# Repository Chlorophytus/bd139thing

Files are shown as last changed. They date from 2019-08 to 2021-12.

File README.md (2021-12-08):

# bd139thing

The BD139 Thing is a 300mW RMS stereo Hi-Fi Class-A amplifier.

It is pairable with a set of very high sensitivity (>90dB) speakers for audio playback.

Distortion analysis has not been done yet, but [THD][total-harmonic-distortion]/[IMD][intermodulation-distortion] is probably 5-10%; most of it is pleasing "tube sound like" distortion, transistorized.

## Current state

I am working on another revision of the design.
The BD139 cascode is modular, meaning it can have many in parallel when paired with a suitable power supply and power filtering capacitors.
Heat dissipation on the negative feedback shunts and power delivery are primary concerns.

[total-harmonic-distortion]: https://en.wikipedia.org/wiki/Total_harmonic_distortion
[intermodulation-distortion]: https://en.wikipedia.org/wiki/Intermodulation

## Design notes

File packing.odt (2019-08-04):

Hey, so you ordered a BD139 Thing. Here’s a Bill of Materials for your convenience, containing part numbers and stuff. A packing list is supplied with this.

If you want to mess around with the design, feel free to contact me.

You can also get the Gerber/KiCad files from the Chlorophytus git repos:

git://git.chlorophyt.us/bd139thing.git

– Roland M.

INSTRUCTIONS ON MAKING:

1. Solder non-power resistors: R1/R2/R3/R4/R6/R7/R8/R9/R11
2. Solder LED: D1
3. Solder headphone jack: J1
4. Solder power jack: J2
5. Solder power resistors: R5/R10
6. Solder speaker terminal blocks: LS1/LS2
7. Solder SMALL capacitors, 47uF: C1/C3
8. Solder BIG capacitors, 2200uF: C2/C4
9. Solder the PN2222s (Q1/Q4) first then the BD139s (Q2/Q3/Q5/Q6)
10. Apply the heatsink on the exposed square.

NOTES:

Use bookshelf speakers that are 4-8 ohms. I don’t have any recommendations.

Use a 9V >3A power supply, center positive.

https://www.digikey.com/product-detail/en/cui-inc/SMI36-9-V-P5/102-3835-ND/5417696

BD139 Thing version v6.0 – packing list

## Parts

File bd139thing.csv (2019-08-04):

Manufacturer Part Number | Digi-Key Part Number | Customer Reference | Quantity
ECA-1HHG222 | P5576-ND | C2/C4 | 2
ECA-1HHG470 | P5570-ND | C1/C3 | 2
1984617 | 277-1721-ND | LS1/LS2 | 2
SJ1-3523NG | CP1-3523NG-ND | J1 | 1
PJ-037A | CP-037A-ND | J2 | 1
BD13916S | BD13916S-ND | Q2/Q3/Q5/Q6 | 4
PN2222ABU | PN2222AFS-ND | Q1/Q4 | 2
CFR-25JB-52-11R | 11QBK-ND | R1/R6 | 2
CFR-25JB-52-2K2 | 2.2KQBK-ND | R3/R8 | 2
CFR-25JB-52-330R | 330QBK-ND | R4/R9 | 2
CFR-25JB-52-620R | 620QBK-ND | R2/R7 | 2
SQP10AJB-16R | 16W-10-ND | R5/R10 | 2
WP7113VRVC1C | 754-2184-ND | D1 | 1
CFR-25JB-52-10K | 10KQBK-ND | R11 | 1
374724B00035G | HS323-ND |  | 1

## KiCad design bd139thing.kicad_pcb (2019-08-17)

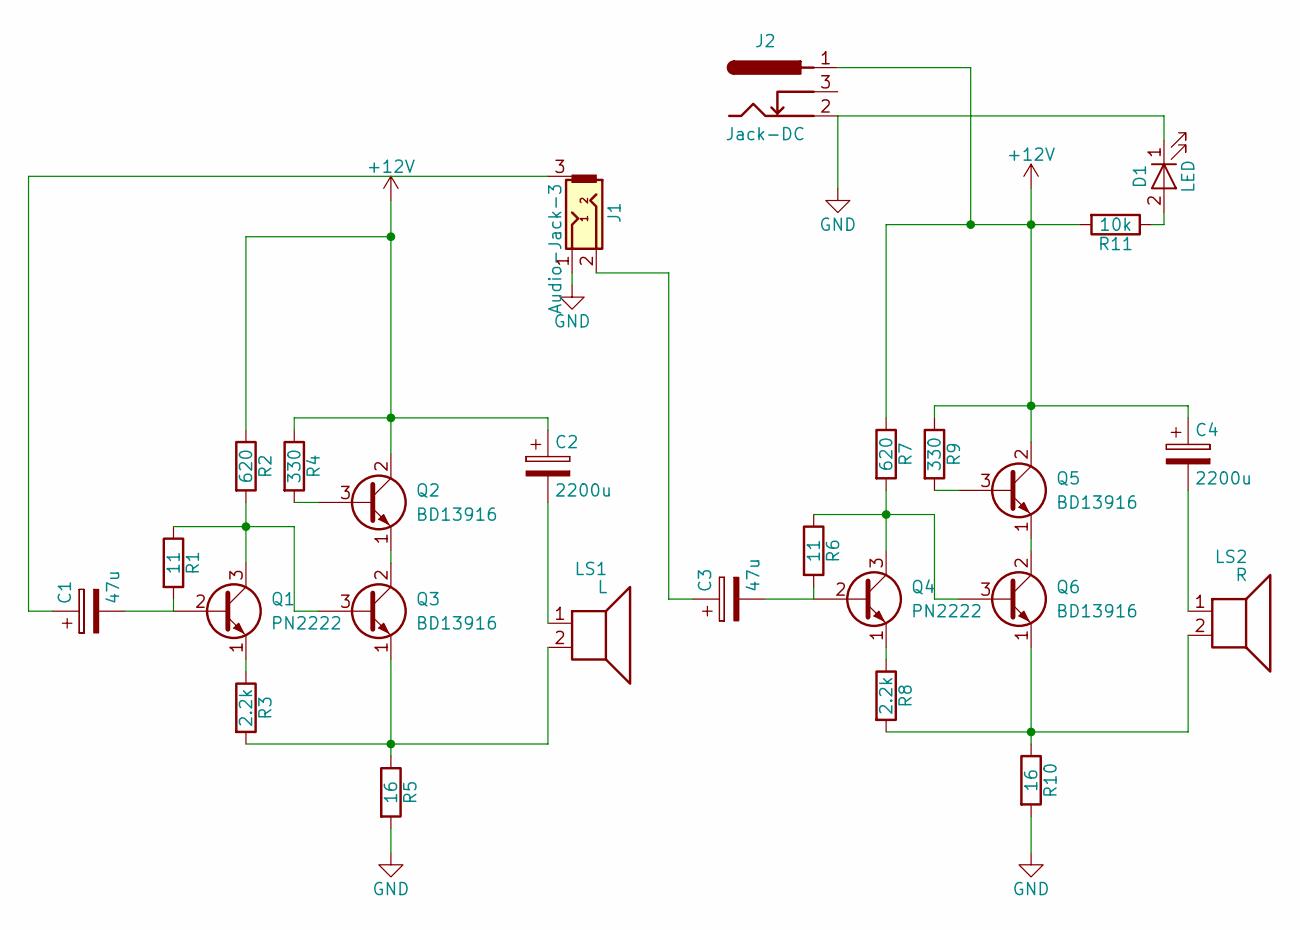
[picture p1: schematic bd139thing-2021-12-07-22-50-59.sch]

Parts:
C1, C3: 47u; ECA-1HHG470
C2, C4: 2200u; ECA-1HHG222
D1: LED; LED_D5.0mm
J1: Audio-Jack-3; CUI_SJ1-3523NG
J2: Jack-DC; CUI_PJ-037A
LS1: L; TerminalBlock_Pheonix_PT-3.5mm_2pol
LS2: R; TerminalBlock_Pheonix_PT-3.5mm_2pol
Q1, Q4: PN2222; TO-92_Inline_Wide
Q2, Q3, Q5, Q6: BD13916; TO-126_Vertical
R1, R6: 11; Resistor_SMD+THTuniversal_0805to1206_RM10_HandSoldering
R2, R7: 620; Resistor_SMD+THTuniversal_0805to1206_RM10_HandSoldering
R3, R8: 2.2k; Resistor_SMD+THTuniversal_0805to1206_RM10_HandSoldering
R4, R9: 330; Resistor_SMD+THTuniversal_0805to1206_RM10_HandSoldering
R5, R10: 16; SQP10AJB-16R
R11: 10k; Resistor_SMD+THTuniversal_0805to1206_RM10_HandSoldering

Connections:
+12V: C2.1, C4.1, J2.1, Q2.2 (C), Q5.2 (C), R2.1, R4.1, R7.1, R9.1, R11.2
GND: D1.1 (K), J1.1, J2.2, R5.2, R10.2
unnamed: C1.1, J1.3
unnamed: C1.2, Q1.2 (B), R1.2
unnamed: C2.2, LS1.1
unnamed: C3.1, J1.2
unnamed: C3.2, Q4.2 (B), R6.2
unnamed: C4.2, LS2.1
unnamed: D1.2 (A), R11.1
unnamed: LS1.2, Q3.1 (E), R3.2, R5.1
unnamed: LS2.2, Q6.1 (E), R8.2, R10.1
unnamed: Q1.1 (E), R3.1
unnamed: Q1.3 (C), Q3.3 (B), R1.1, R2.2
unnamed: Q2.1 (E), Q3.2 (C)
unnamed: Q2.3 (B), R4.2
unnamed: Q4.1 (E), R8.1
unnamed: Q4.3 (C), Q6.3 (B), R6.1, R7.2
unnamed: Q5.1 (E), Q6.2 (C)
unnamed: Q5.3 (B), R9.2

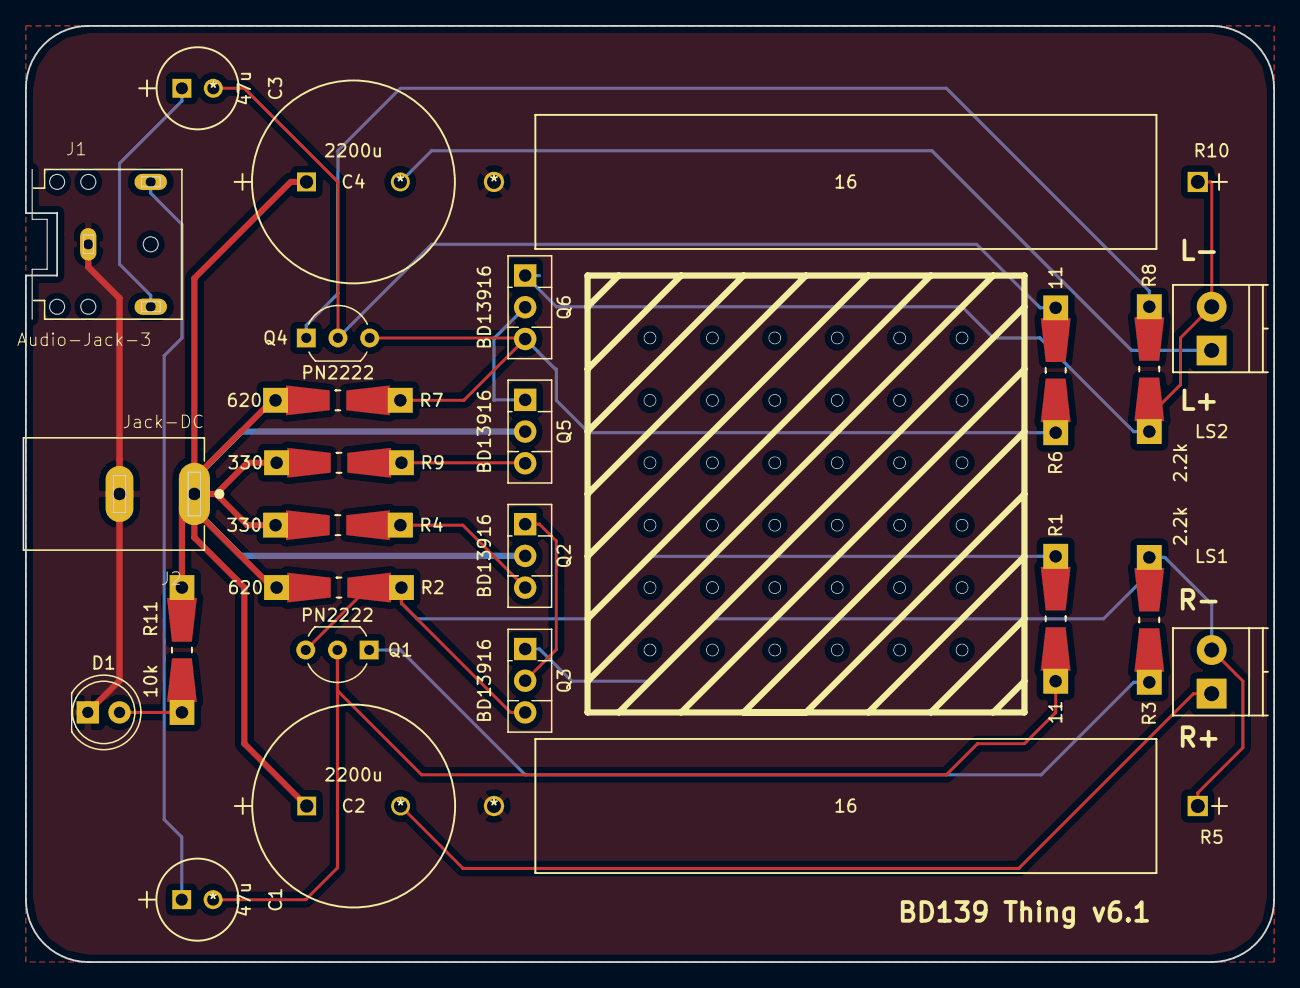
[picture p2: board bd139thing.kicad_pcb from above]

Board: 2 copper layers, 100.0 x 75.0 mm, 26 parts (0 on the bottom side), 19 nets.

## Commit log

2019-07-19 add initial r4p0 ok
    [bd139thing.csv, bd139thing.kicad_pcb, bd139thing.sch]
2019-07-22 r5p0 ok, improved placement on 75x75mm
    [bd139thing.csv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]
2019-07-26 prepare fixes p1
    [bd139thing-B.Cu.gbl, bd139thing-B.Mask.gbs, bd139thing-B.SilkS.gbo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]
2019-07-26 correct problems thx ok r5p2
    [bd139thing-B.Cu.gbl, bd139thing-B.Mask.gbs, bd139thing-B.SilkS.gbo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]
2019-08-04 6 ok
    [bd139thing.csv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]
2019-08-06 ahgod if you know what happened you wouldn't be happy
    [bd139thing-B.Cu.gbl, bd139thing-B.Mask.gbs, bd139thing-B.SilkS.gbo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]
2019-08-17 design wasn't performing as planned
    [bd139thing-B.Cu.gbl, bd139thing-B.Mask.gbs, bd139thing-B.SilkS.gbo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]
2021-12-08 New symbols for simulating are in
    [bd139thing-2021-12-07-22-50-59.sch]

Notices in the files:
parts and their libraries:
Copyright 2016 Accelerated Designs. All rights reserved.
